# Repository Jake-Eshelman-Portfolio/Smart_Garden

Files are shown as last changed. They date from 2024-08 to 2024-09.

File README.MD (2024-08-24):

# Plant Watering System with the STM32F429 MCU

## Overview
This project automates the watering of plants using an STM32F429 Development Kit, PWM controlled DC motor, and an I2C moisture sensor.
The skills I wanted to work on in this project were learning STM microctrollers, working with PWM signals, I2C communication, and power supplies.

## Features
- Soil moisture monitoring 
- Automated watering using a step-controlled motor and a control system to maintain moisture levels
- Configurable low-power mode and RTC-interrupt generation

## Components
- STM32F429 Development Kit (https://www.digikey.com/en/products/detail/stmicroelectronics/STM32F429I-DISC1/5731713) 
- Capacitive soil moisture sensors -- https://www.tindie.com/products/miceuz/i2c-soil-moisture-sensor/, documentation: https://github.com/Miceuz/i2c-moisture-sensor/blob/master/README.md, also purchased 4 pin 90 degree header to attach
- Small water pump -- Gikfun 12V DC Dosing Pump Peristaltic (Amazon)
    - Tubing -- Gikfun 9.84 Ft 2mm x 4mm tubing (Amazon)
    - Power supply --  Kastar AC power adapter 12V 6A (Amazon)
- L298N motor driver (Amazon)

## Schematic
- The I2C connector used in the project is not present in Fritzing, and a generic I2C sensor was used in its place to demonstrate pin connections
- Fritzing diagram included: diagrams/breadbiard_diagram.fzz
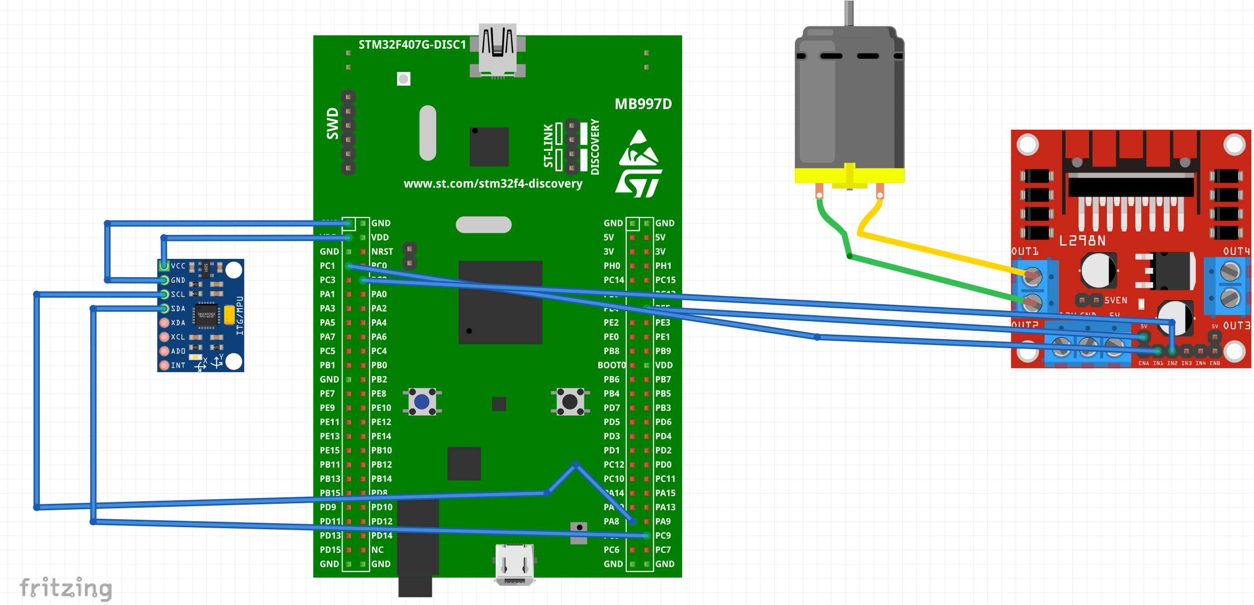
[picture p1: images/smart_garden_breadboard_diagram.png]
Fritzing Breadboard Diagram


### Building and Flashing
- The project was built using STM32CubeMX with default settings for the board: STM32F429ZITx - STM32F429I-DISC1 except for PWM, GPIO, and I2C changes.
    - I2C3 was added with GPIO pullups configured. 
        - SCL: PA8 
        - SDA: PC9
    - TIM9 was configured with PWM generation on CH1 on pin PE5
        1. Calculating PWM Frequency: APB1 Frequency = (Desired PWM Frequency) * (Prescalar + 1) * (Auto reload register + 1)
            - 72,000,000 = 10,000 * (PSC + 1) * (ARR + 1)
                - PSC = 71 (For easy calculation),
                - ARR = 99 to give 10kHZ PWM frequency
        2. Duty Cycle = Counter Period (ARR) / X
            - X = 2 -> 50% Duty Cycle
        3. Motor output GPIOS:
            - PC1, PC2 configured as:
                - output level: low, push pull, no pull-up/pull-down

- The project was built for STM32CubeIDE

## Progress
- Video folder: https://drive.google.com/drive/u/0/folders/1cJCFLaSTaK_Rhd7NLPWWA5U1GQ5bJ7LP

- Complete working demo! (8/23/24)
https://drive.google.com/file/d/12AGUKqzUinZLPr214EPg7lUeSSH95k2j/view?usp=sharing

- Currently the motor driver is connected and functioning correctly. Still waiting on the moisture sensor to arrive to build out feedback / control systems (8/1/24).
https://drive.google.com/file/d/1gY22B0iSNcU8m8TwlX8VpE6k7BG8msSk/view?usp=drive_link

## Future Enhancements
- LCD screen for displaying plant watering status
- IoT / mobile app component for managing plants while away
- Extension to handling multiple plants
- Custom PCB / Case

## External Documentation
- L298N Motor Driver Datasheet: https://components101.com/sites/default/files/component_datasheet/L298N-Motor-Driver-Datasheet.pdf
- STM32F4 HAL and low-layer driver description: https://www.st.com/resource/en/user_manual/um1725-description-of-stm32f4-hal-and-lowlayer-drivers-stmicroelectronics.pdf
- STM32F4 HAL user manual GPIO: https://www.disca.upv.es/aperles/arm_cortex_m3/llibre/st/STM32F439xx_User_Manual/group__gpio__exported__functions__group2.html
- STM32F4 HAL user manual I2C: https://www.disca.upv.es/aperles/arm_cortex_m3/llibre/st/STM32F439xx_User_Manual/group__i2c__exported__functions__group2.html

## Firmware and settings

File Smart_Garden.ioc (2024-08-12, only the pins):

Mcu.UserName=STM32F429ZITx
PA0/WKUP.GPIO_Label=B1 [Blue PushButton]
PA0/WKUP.Signal=GPXTI0
PA1.GPIO_Label=MEMS_INT1 [L3GD20_INT1]
PA1.Signal=GPXTI1
PA10.GPIO_Label=STLINK_TX [STM32F103CBT6_PA2]
PA10.Signal=USART1_RX
PA11.GPIO_Label=R4
PA11.Signal=LTDC_R4
PA12.GPIO_Label=R5
PA12.Signal=LTDC_R5
PA13.GPIO_Label=SWDIO
PA13.Signal=SYS_JTMS-SWDIO
PA14.GPIO_Label=SWCLK
PA14.Signal=SYS_JTCK-SWCLK
PA15.GPIO_Label=TP_INT1 [Touch Panel]
PA15.Signal=GPXTI15
PA2.GPIO_Label=MEMS_INT2 [L3GD20_INT2]
PA2.Signal=GPXTI2
PA3.GPIO_Label=B5
PA3.Signal=LTDC_B5
PA4.GPIO_Label=VSYNC
PA4.Signal=LTDC_VSYNC
PA5.Signal=ADCx_IN5
PA6.GPIO_Label=G2
PA6.Signal=LTDC_G2
PA7.GPIO_Label=ACP_RST
PA7.Signal=GPIO_Output
PA8.GPIO_Label=I2C3_SCL [ACP/RF_SCL]
PA8.Signal=I2C3_SCL
PA9.GPIO_Label=STLINK_RX [STM32F103CBT6_PA3]
PA9.Signal=USART1_TX
PB0.GPIO_Label=R3
PB0.Signal=LTDC_R3
PB1.GPIO_Label=R6
PB1.Signal=LTDC_R6
PB10.GPIO_Label=G4
PB10.Signal=LTDC_G4
PB11.GPIO_Label=G5
PB11.Signal=LTDC_G5
PB12.GPIO_Label=OTG_HS_ID
PB12.Signal=USB_OTG_HS_ID
PB13.GPIO_Label=VBUS_HS
PB13.Signal=USB_OTG_HS_VBUS
PB14.GPIO_Label=OTG_HS_DM
PB14.Signal=USB_OTG_HS_DM
PB15.GPIO_Label=OTG_HS_DP
PB15.Signal=USB_OTG_HS_DP
PB2/BOOT1.GPIO_Label=BOOT1
PB2/BOOT1.Signal=GPIO_Input
PB5.GPIO_Label=SDCKE1
PB5.Signal=FMC_SDCKE1
PB6.GPIO_Label=SDNE1 [SDRAM_CS]
PB6.Signal=FMC_SDNE1
PB8.GPIO_Label=B6
PB8.Signal=LTDC_B6
PB9.GPIO_Label=B7
PB9.Signal=LTDC_B7
PC0.GPIO_Label=SDNWE
PC0.Signal=FMC_SDNWE
PC1.GPIO_Label=Motor1
PC1.Signal=GPIO_Output
PC10.GPIO_Label=R2
PC10.Signal=LTDC_R2
PC14/OSC32_IN.GPIO_Label=PC14-OSC32_IN
PC14/OSC32_IN.Signal=RCC_OSC32_IN
PC15/OSC32_OUT.GPIO_Label=PC15-OSC32_OUT
PC15/OSC32_OUT.Signal=RCC_OSC32_OUT
PC2.GPIO_Label=Motor2
PC2.Signal=GPIO_Output
PC4.GPIO_Label=OTG_FS_PSO [OTG_FS_PowerSwitchOn]
PC4.Signal=GPIO_Output
PC5.GPIO_Label=OTG_FS_OC [OTG_FS_OverCurrent]
PC5.Signal=GPXTI5
PC6.GPIO_Label=HSYNC
PC6.Signal=LTDC_HSYNC
PC7.GPIO_Label=G6
PC7.Signal=LTDC_G6
PC9.GPIO_Label=I2C3_SDA [ACP/RF_SDA]
PC9.Signal=I2C3_SDA
PD0.GPIO_Label=D2
PD0.Signal=FMC_D2_DA2
PD1.GPIO_Label=D3
PD1.Signal=FMC_D3_DA3
PD10.GPIO_Label=D15
PD10.Signal=FMC_D15_DA15
PD11.GPIO_Label=TE [LCD-RGB_TE]
PD11.Signal=GPIO_Input
PD12.GPIO_Label=RDX [LDC-RGB_RDX]
PD12.Signal=GPIO_Output
PD13.GPIO_Label=WRX_DCX [LCD-RGB_WRX_DCX]
PD13.Signal=GPIO_Output
PD14.GPIO_Label=D0
PD14.Signal=FMC_D0_DA0
PD15.GPIO_Label=D1
PD15.Signal=FMC_D1_DA1
PD3.GPIO_Label=G7
PD3.Signal=LTDC_G7
PD6.GPIO_Label=B2
PD6.Signal=LTDC_B2
PD8.GPIO_Label=D13
PD8.Signal=FMC_D13_DA13
PD9.GPIO_Label=D14
PD9.Signal=FMC_D14_DA14
PE0.GPIO_Label=NBL0 [SDRAM_LDQM]
PE0.Signal=FMC_NBL0
PE1.GPIO_Label=NBL1 [SDRAM_UDQM]
PE1.Signal=FMC_NBL1
PE10.GPIO_Label=D7
PE10.Signal=FMC_D7_DA7
PE11.GPIO_Label=D8
PE11.Signal=FMC_D8_DA8
PE12.GPIO_Label=D9
PE12.Signal=FMC_D9_DA9
PE13.GPIO_Label=D10
PE13.Signal=FMC_D10_DA10
PE14.GPIO_Label=D11
PE14.Signal=FMC_D11_DA11
PE15.GPIO_Label=D12
PE15.Signal=FMC_D12_DA12
PE5.Signal=S_TIM9_CH1
PE7.GPIO_Label=D4
PE7.Signal=FMC_D4_DA4
PE8.GPIO_Label=D5
PE8.Signal=FMC_D5_DA5
PE9.GPIO_Label=D6
PE9.Signal=FMC_D6_DA6
PF0.GPIO_Label=A0
PF0.Signal=FMC_A0
PF1.GPIO_Label=A1
PF1.Signal=FMC_A1
PF10.GPIO_Label=ENABLE [LCD-RGB_ENABLE]
PF10.Signal=LTDC_DE
PF11.GPIO_Label=SDNRAS
PF11.Signal=FMC_SDNRAS
PF12.GPIO_Label=A6
PF12.Signal=FMC_A6
PF13.GPIO_Label=A7
PF13.Signal=FMC_A7
PF14.GPIO_Label=A8
PF14.Signal=FMC_A8
PF15.GPIO_Label=A9
PF15.Signal=FMC_A9
PF2.GPIO_Label=A2
PF2.Signal=FMC_A2
PF3.GPIO_Label=A3
PF3.Signal=FMC_A3
PF4.GPIO_Label=A4
PF4.Signal=FMC_A4
PF5.GPIO_Label=A5
PF5.Signal=FMC_A5
PF7.GPIO_Label=SPI5_SCK [L3GD20_SCL/SPC]
PF7.Signal=SPI5_SCK
PF8.GPIO_Label=SPI5_MISO [L3GD20_SDO]
PF8.Signal=SPI5_MISO
PF9.GPIO_Label=SPI5_MOSI [L3GD20_SDA/SDI/SDO]
PF9.Signal=SPI5_MOSI
PG0.GPIO_Label=A10
PG0.Signal=FMC_A10
PG1.GPIO_Label=A11
PG1.Signal=FMC_A11
PG10.GPIO_Label=G3
PG10.Signal=LTDC_G3
PG11.GPIO_Label=B3
PG11.Signal=LTDC_B3
PG12.GPIO_Label=B4
PG12.Signal=LTDC_B4
PG13.GPIO_Label=LD3 [Green Led]
PG13.Signal=GPIO_Output
PG14.GPIO_Label=LD4 [Red Led]
PG14.Signal=GPIO_Output
PG15.GPIO_Label=SDNCAS
PG15.Signal=FMC_SDNCAS
PG4.GPIO_Label=BA0
PG4.Signal=FMC_A14_BA0
PG5.GPIO_Label=BA1
PG5.Signal=FMC_A15_BA1
PG6.GPIO_Label=R7
PG6.Signal=LTDC_R7
PG7.GPIO_Label=DOTCLK [LCT-RGB_DOTCLK]
PG7.Signal=LTDC_CLK
PG8.GPIO_Label=SDCLK
PG8.Signal=FMC_SDCLK
PH0/OSC_IN.GPIO_Label=PH0-OSC_IN
PH0/OSC_IN.Signal=RCC_OSC_IN
PH1/OSC_OUT.GPIO_Label=PH1-OSC_OUT
PH1/OSC_OUT.Signal=RCC_OSC_OUT

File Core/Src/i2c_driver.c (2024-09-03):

/*
 * motor_driver.c
 *
 *  Created on: Aug 1, 2024
 *      Author: jakee
 */

#include "i2c_driver.h"
#include "stm32f4xx_hal.h"
#include "main.h"
#include <stdio.h>
#include <stdint.h>

I2C_HandleTypeDef hi2c3;


/**
  * @brief I2C3 Initialization Function
  * @param None
  * @retval None
  */
void MX_I2C3_Init(void)
{
  hi2c3.Instance = I2C3;
  hi2c3.Init.ClockSpeed = 30000; 
  hi2c3.Init.DutyCycle = I2C_DUTYCYCLE_2;
  hi2c3.Init.OwnAddress1 = 0;
  hi2c3.Init.AddressingMode = I2C_ADDRESSINGMODE_7BIT;
  hi2c3.Init.DualAddressMode = I2C_DUALADDRESS_DISABLE;
  hi2c3.Init.OwnAddress2 = 0;
  hi2c3.Init.GeneralCallMode = I2C_GENERALCALL_DISABLE;
  hi2c3.Init.NoStretchMode = I2C_NOSTRETCH_DISABLE;
  if (HAL_I2C_Init(&hi2c3) != HAL_OK)
  {
    Error_Handler();
  }

  /** Configure Analogue filter
  */
  if (HAL_I2CEx_ConfigAnalogFilter(&hi2c3, I2C_ANALOGFILTER_ENABLE) != HAL_OK)
  {
    Error_Handler();
  }

  /** Configure Digital filter
  */
  if (HAL_I2CEx_ConfigDigitalFilter(&hi2c3, 0) != HAL_OK)
  {
    Error_Handler();
  }
}

/**
  * @brief Function to read the temperature from the sensor
  * @param None
  * @retval None
  */
void read_temperature()
{
	uint8_t temperature_data[2];
	uint8_t busy_data = 1;

	HAL_StatusTypeDef status;

	// Sensor reads once for previous value then updates with recent value. Get old value first to update register.
	status = HAL_I2C_Mem_Read(&hi2c3, SENSOR_ADDRESS << 1, TEMPERATURE_REGISTER,
			I2C_MEMADD_SIZE_8BIT, temperature_data, TEMPERATURE_READ_SIZE,
			HAL_MAX_DELAY);

	if (status != HAL_OK) {
		printf("Initial temperature read failed with status: %d \r\n", status);
		return;
	}

    // Wait for measurement to complete
    while (busy_data == 1)
    {
        HAL_I2C_Mem_Read(&hi2c3, SENSOR_ADDRESS << 1 , BUSY_REGISTER, I2C_MEMADD_SIZE_8BIT, &busy_data, BUSY_DATA_SIZE, HAL_MAX_DELAY);
        HAL_Delay(10); // Short delay to avoid flooding the I2C bus
    }

	// Read the updated temperature value and print it on success
	status = HAL_I2C_Mem_Read(&hi2c3, SENSOR_ADDRESS << 1, TEMPERATURE_REGISTER, I2C_MEMADD_SIZE_8BIT, temperature_data, TEMPERATURE_READ_SIZE, HAL_MAX_DELAY);
	if (status == HAL_OK)
	{
		uint16_t combined_temperature = temperature_data[0] << 8 | temperature_data[1];
		printf("Temperature: %d \r\n", combined_temperature);
	}
	else
	{
		printf("Temperature read failed with status: %d \r\n", status);
	}
}


/**
  * @brief Function to read the capacitance from the sensor
  * @param None
  * @retval int16_t as the capactiance from the sensor
  */
int16_t read_capacitance()
{
	uint8_t capacitance_data[2];
	uint8_t busy_data = 1;
	int16_t combined_capacitance;

	HAL_StatusTypeDef status;

	// Sensor reads once for previous value then updates with recent value. Get old value first to update register.
	status = HAL_I2C_Mem_Read(&hi2c3, SENSOR_ADDRESS << 1, CAPACITANCE_REGISTER, I2C_MEMADD_SIZE_8BIT, capacitance_data, CAPACITANCE_READ_SIZE, HAL_MAX_DELAY);

	if (status != HAL_OK) {
		printf("Initial capacitance read failed with status: %d \r\n", status);
		return I2C_READ_FAIL;
	}

    // Wait for measurement to complete
    while (busy_data == 1)
    {
        HAL_I2C_Mem_Read(&hi2c3, SENSOR_ADDRESS << 1 , BUSY_REGISTER, I2C_MEMADD_SIZE_8BIT, &busy_data, BUSY_DATA_SIZE, HAL_MAX_DELAY);
        HAL_Delay(10); 
    }

	// Read the updated capacitance value and print it on success
	status = HAL_I2C_Mem_Read(&hi2c3, SENSOR_ADDRESS << 1, CAPACITANCE_REGISTER, I2C_MEMADD_SIZE_8BIT, capacitance_data, CAPACITANCE_READ_SIZE, HAL_MAX_DELAY);
	if (status == HAL_OK)
	{
		combined_capacitance = capacitance_data[0] << 8 | capacitance_data[1];
		printf("Capacitance: %d \r\n", combined_capacitance);
	}
	else
	{
		printf("Capacitance read failed with status: %d \r\n", status);
		return I2C_READ_FAIL;
	}
	return combined_capacitance;
}

void sensor_diagnostic()
{
    uint8_t data[2];
    HAL_StatusTypeDef status;

    // Read sensor version
    status = HAL_I2C_Mem_Read(&hi2c3, SENSOR_ADDRESS << 1, 0x07, I2C_MEMADD_SIZE_8BIT, data, 1, HAL_MAX_DELAY);
    printf("Sensor version: 0x%02X, Status: %d\r\n", data[0], status);

    // Reset sensor
    status = HAL_I2C_Mem_Write(&hi2c3, SENSOR_ADDRESS << 1, RESET_REGISTER, I2C_MEMADD_SIZE_8BIT, NULL, 0, HAL_MAX_DELAY);
    printf("Reset status: %d\r\n", status);
    HAL_Delay(100);


    // Read light
    status = HAL_I2C_Mem_Read(&hi2c3, SENSOR_ADDRESS << 1, 0x04, I2C_MEMADD_SIZE_8BIT, data, 2, HAL_MAX_DELAY);
    if (status == HAL_OK) {
        uint16_t light = (data[0] << 8) | data[1];
        printf("Light raw: %d \r\n", light);
    } else {
        printf("Light read failed, status: %d\r\n", status);
    }
}

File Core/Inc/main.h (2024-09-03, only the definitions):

#define PC14_OSC32_IN_Pin GPIO_PIN_14
#define PC14_OSC32_IN_GPIO_Port GPIOC
#define PC15_OSC32_OUT_Pin GPIO_PIN_15
#define PC15_OSC32_OUT_GPIO_Port GPIOC
#define A0_Pin GPIO_PIN_0
#define A0_GPIO_Port GPIOF
#define A1_Pin GPIO_PIN_1
#define A1_GPIO_Port GPIOF
#define A2_Pin GPIO_PIN_2
#define A2_GPIO_Port GPIOF
#define A3_Pin GPIO_PIN_3
#define A3_GPIO_Port GPIOF
#define A4_Pin GPIO_PIN_4
#define A4_GPIO_Port GPIOF
#define A5_Pin GPIO_PIN_5
#define A5_GPIO_Port GPIOF
#define SPI5_SCK_Pin GPIO_PIN_7
#define SPI5_SCK_GPIO_Port GPIOF
#define SPI5_MISO_Pin GPIO_PIN_8
#define SPI5_MISO_GPIO_Port GPIOF
#define SPI5_MOSI_Pin GPIO_PIN_9
#define SPI5_MOSI_GPIO_Port GPIOF
#define ENABLE_Pin GPIO_PIN_10
#define ENABLE_GPIO_Port GPIOF
#define PH0_OSC_IN_Pin GPIO_PIN_0
#define PH0_OSC_IN_GPIO_Port GPIOH
#define PH1_OSC_OUT_Pin GPIO_PIN_1
#define PH1_OSC_OUT_GPIO_Port GPIOH
#define SDNWE_Pin GPIO_PIN_0
#define SDNWE_GPIO_Port GPIOC
#define Motor1_Pin GPIO_PIN_1
#define Motor1_GPIO_Port GPIOC
#define Motor2_Pin GPIO_PIN_2
#define Motor2_GPIO_Port GPIOC
#define B1_Pin GPIO_PIN_0
#define B1_GPIO_Port GPIOA
#define MEMS_INT1_Pin GPIO_PIN_1
#define MEMS_INT1_GPIO_Port GPIOA
#define MEMS_INT2_Pin GPIO_PIN_2
#define MEMS_INT2_GPIO_Port GPIOA
#define B5_Pin GPIO_PIN_3
#define B5_GPIO_Port GPIOA
#define VSYNC_Pin GPIO_PIN_4
#define VSYNC_GPIO_Port GPIOA
#define G2_Pin GPIO_PIN_6
#define G2_GPIO_Port GPIOA
#define ACP_RST_Pin GPIO_PIN_7
#define ACP_RST_GPIO_Port GPIOA
#define OTG_FS_PSO_Pin GPIO_PIN_4
#define OTG_FS_PSO_GPIO_Port GPIOC
#define OTG_FS_OC_Pin GPIO_PIN_5
#define OTG_FS_OC_GPIO_Port GPIOC
#define R3_Pin GPIO_PIN_0
#define R3_GPIO_Port GPIOB
#define R6_Pin GPIO_PIN_1
#define R6_GPIO_Port GPIOB
#define BOOT1_Pin GPIO_PIN_2
#define BOOT1_GPIO_Port GPIOB
#define SDNRAS_Pin GPIO_PIN_11
#define SDNRAS_GPIO_Port GPIOF
#define A6_Pin GPIO_PIN_12
#define A6_GPIO_Port GPIOF
#define A7_Pin GPIO_PIN_13
#define A7_GPIO_Port GPIOF
#define A8_Pin GPIO_PIN_14
#define A8_GPIO_Port GPIOF
#define A9_Pin GPIO_PIN_15
#define A9_GPIO_Port GPIOF
#define A10_Pin GPIO_PIN_0
#define A10_GPIO_Port GPIOG
#define A11_Pin GPIO_PIN_1
#define A11_GPIO_Port GPIOG
#define D4_Pin GPIO_PIN_7
#define D4_GPIO_Port GPIOE
#define D5_Pin GPIO_PIN_8
#define D5_GPIO_Port GPIOE
#define D6_Pin GPIO_PIN_9
#define D6_GPIO_Port GPIOE
#define D7_Pin GPIO_PIN_10
#define D7_GPIO_Port GPIOE
#define D8_Pin GPIO_PIN_11
#define D8_GPIO_Port GPIOE
#define D9_Pin GPIO_PIN_12
#define D9_GPIO_Port GPIOE
#define D10_Pin GPIO_PIN_13
#define D10_GPIO_Port GPIOE
#define D11_Pin GPIO_PIN_14
#define D11_GPIO_Port GPIOE
#define D12_Pin GPIO_PIN_15
#define D12_GPIO_Port GPIOE
#define G4_Pin GPIO_PIN_10
#define G4_GPIO_Port GPIOB
#define G5_Pin GPIO_PIN_11
#define G5_GPIO_Port GPIOB
#define OTG_HS_ID_Pin GPIO_PIN_12
#define OTG_HS_ID_GPIO_Port GPIOB
#define VBUS_HS_Pin GPIO_PIN_13
#define VBUS_HS_GPIO_Port GPIOB
#define OTG_HS_DM_Pin GPIO_PIN_14
#define OTG_HS_DM_GPIO_Port GPIOB
#define OTG_HS_DP_Pin GPIO_PIN_15
#define OTG_HS_DP_GPIO_Port GPIOB
#define D13_Pin GPIO_PIN_8
#define D13_GPIO_Port GPIOD
#define D14_Pin GPIO_PIN_9
#define D14_GPIO_Port GPIOD
#define D15_Pin GPIO_PIN_10
#define D15_GPIO_Port GPIOD
#define TE_Pin GPIO_PIN_11
#define TE_GPIO_Port GPIOD
#define RDX_Pin GPIO_PIN_12
#define RDX_GPIO_Port GPIOD
#define WRX_DCX_Pin GPIO_PIN_13
#define WRX_DCX_GPIO_Port GPIOD
#define D0_Pin GPIO_PIN_14
#define D0_GPIO_Port GPIOD
#define D1_Pin GPIO_PIN_15
#define D1_GPIO_Port GPIOD
#define BA0_Pin GPIO_PIN_4
#define BA0_GPIO_Port GPIOG
#define BA1_Pin GPIO_PIN_5
#define BA1_GPIO_Port GPIOG
#define R7_Pin GPIO_PIN_6
#define R7_GPIO_Port GPIOG
#define DOTCLK_Pin GPIO_PIN_7
#define DOTCLK_GPIO_Port GPIOG
#define SDCLK_Pin GPIO_PIN_8
#define SDCLK_GPIO_Port GPIOG
#define HSYNC_Pin GPIO_PIN_6
#define HSYNC_GPIO_Port GPIOC
#define G6_Pin GPIO_PIN_7
#define G6_GPIO_Port GPIOC
#define I2C3_SDA_Pin GPIO_PIN_9
#define I2C3_SDA_GPIO_Port GPIOC
#define I2C3_SCL_Pin GPIO_PIN_8
#define I2C3_SCL_GPIO_Port GPIOA
#define STLINK_RX_Pin GPIO_PIN_9
#define STLINK_RX_GPIO_Port GPIOA
#define STLINK_TX_Pin GPIO_PIN_10
#define STLINK_TX_GPIO_Port GPIOA
#define R4_Pin GPIO_PIN_11
#define R4_GPIO_Port GPIOA
#define R5_Pin GPIO_PIN_12
#define R5_GPIO_Port GPIOA
#define SWDIO_Pin GPIO_PIN_13
#define SWDIO_GPIO_Port GPIOA
#define SWCLK_Pin GPIO_PIN_14
#define SWCLK_GPIO_Port GPIOA
#define TP_INT1_Pin GPIO_PIN_15
#define TP_INT1_GPIO_Port GPIOA
#define R2_Pin GPIO_PIN_10
#define R2_GPIO_Port GPIOC
#define D2_Pin GPIO_PIN_0
#define D2_GPIO_Port GPIOD
#define D3_Pin GPIO_PIN_1
#define D3_GPIO_Port GPIOD
#define G7_Pin GPIO_PIN_3
#define G7_GPIO_Port GPIOD
#define B2_Pin GPIO_PIN_6
#define B2_GPIO_Port GPIOD
#define G3_Pin GPIO_PIN_10
#define G3_GPIO_Port GPIOG
#define B3_Pin GPIO_PIN_11
#define B3_GPIO_Port GPIOG
#define B4_Pin GPIO_PIN_12
#define B4_GPIO_Port GPIOG
#define LD3_Pin GPIO_PIN_13
#define LD3_GPIO_Port GPIOG
#define LD4_Pin GPIO_PIN_14
#define LD4_GPIO_Port GPIOG
#define SDNCAS_Pin GPIO_PIN_15
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

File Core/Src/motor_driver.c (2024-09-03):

/*
 * motor_driver.c
 *
 *  Created on: Aug 1, 2024
 *      Author: jakee
 */
/*
 * GPIO_PIN_1 = PC1
 * GPIO_PIN_2 = PC2
 *
 *
 */
#include "motor_driver.h"
#include "stm32f4xx_hal.h"
#include "main.h"
#include <stdint.h>



// Global variables
extern TIM_HandleTypeDef htim9;  

void Motor_Init(void)
{
    // Start PWM on PE5
    HAL_TIM_PWM_Start(&htim9, TIM_CHANNEL_1);  
}

void Motor_SetSpeed(uint16_t speed)
{
    // 16-bit timer
    __HAL_TIM_SET_COMPARE(&htim9, TIM_CHANNEL_1, speed);
}

void Motor_Forward(void)
{
    HAL_GPIO_WritePin(Motor1_GPIO_Port, Motor1_Pin, GPIO_PIN_SET);
    HAL_GPIO_WritePin(Motor2_GPIO_Port, Motor2_Pin, GPIO_PIN_RESET);
}

void Motor_Backward(void)
{
    HAL_GPIO_WritePin(Motor1_GPIO_Port, Motor1_Pin, GPIO_PIN_RESET);
    HAL_GPIO_WritePin(Motor2_GPIO_Port, Motor2_Pin, GPIO_PIN_SET);
}

void Motor_Stop(void)
{
    HAL_GPIO_WritePin(Motor1_GPIO_Port, Motor1_Pin, GPIO_PIN_RESET);
    HAL_GPIO_WritePin(Motor2_GPIO_Port, Motor2_Pin, GPIO_PIN_RESET);
}

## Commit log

2024-07-28 added build in stm32cube mx ported to stm32cubeIDE. hello world program configured and verified printing over uart.
2024-08-01 updated STM32CubeMX to handle PWM (see readme) and updated reame accordingly
2024-08-01 added motor_driver.c and .h files and simple functions for motor control. build succeeds but currently not tested
2024-08-01 updated motor pins to be PC1 and PC2, signal sending correctly but motor not moving
    [Smart_Garden.ioc, main.h, motor_driver.c]
2024-08-01 basic motor functionality working
2024-08-01 added documentation for fritizing diagram
    [breadboard_diagram.fzz]
2024-08-01 added images and diagrams, updated readme
    [breadboard_diagram.fzz]
2024-08-05 added i2c driver.c and i2c_driver.h files. moved init to i2c_driver file. added basic read temp function that is not well tested but is returning successfully. repeated calls seem to cause issues
    [i2c_driver.c]
2024-08-05 multiple reads and correct temp value reading consistently. added handling busy status as well as getting most recent time before providing temp value
    [i2c_driver.c]
2024-08-05 added and tested capacitance read, functioning properly. Air = 210, Dry soil 225, Wet soil approx 450 stabilizing to around 300
2024-08-06 regenerating code in stm32cubemx removed my code for redirecting printf to uart and had to be placed back, and also move i2c back out of main
2024-08-12 rtc wakeup prototype working
    [breadboard_diagram.fzz]
2024-08-23 code used during demo, all components functioning correctly, needs some code cleanup
    [i2c_driver.c, main.h]
2024-09-03 updated logic for handling water feedback control
    [breadboard_diagram.fzz]
2024-09-03 removed added cubeMX comments, fixed magic numbers, formatting fixes
    [i2c_driver.c, main.h, motor_driver.c]
